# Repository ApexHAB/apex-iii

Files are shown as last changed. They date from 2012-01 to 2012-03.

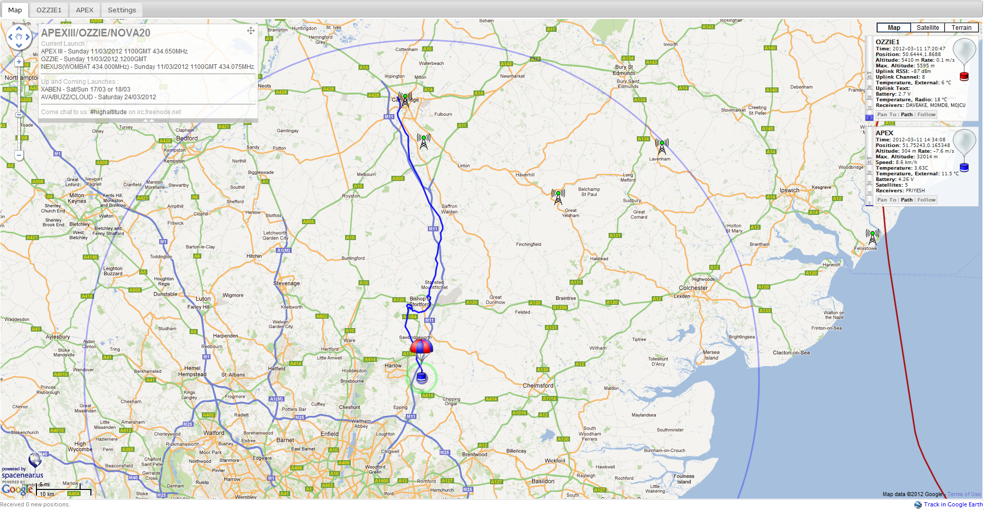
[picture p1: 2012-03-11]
launches/launch-2/track/ApexIIILaunch2-Track (1).png

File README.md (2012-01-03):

# Apex III
## A next generation high altitude balloon project by Sutton Grammar School

## Useful links

* [Homepage](http://www.apexhab.org) - http://www.apexhab.org
* [Apex III Homepage](http://www.apexhab.org/apex-iii/) - http://www.apexhab.org/apex-iii/
* [Contact](mailto:team@apexhab.org) - team@apexhab.org
* [Twitter](http://twitter.com/apexhab) - http://twitter.com/apexhab

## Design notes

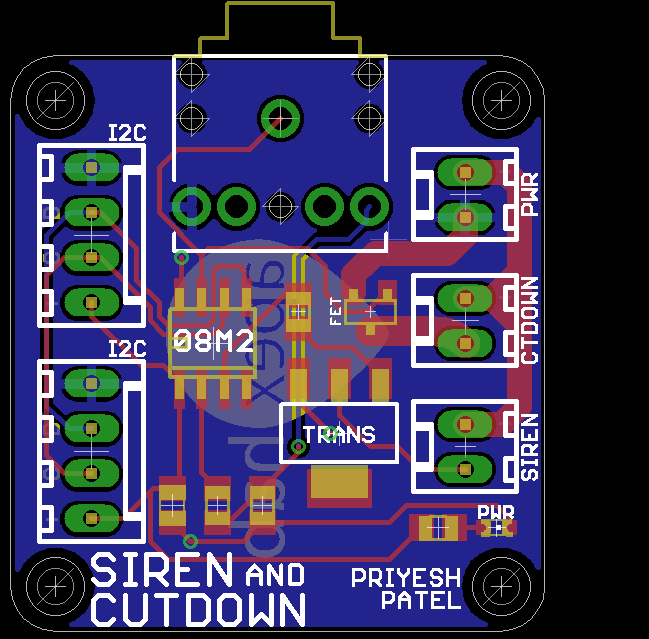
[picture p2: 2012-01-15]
modules/siren_cutdown/pcb/siren-cutdown-brd.png

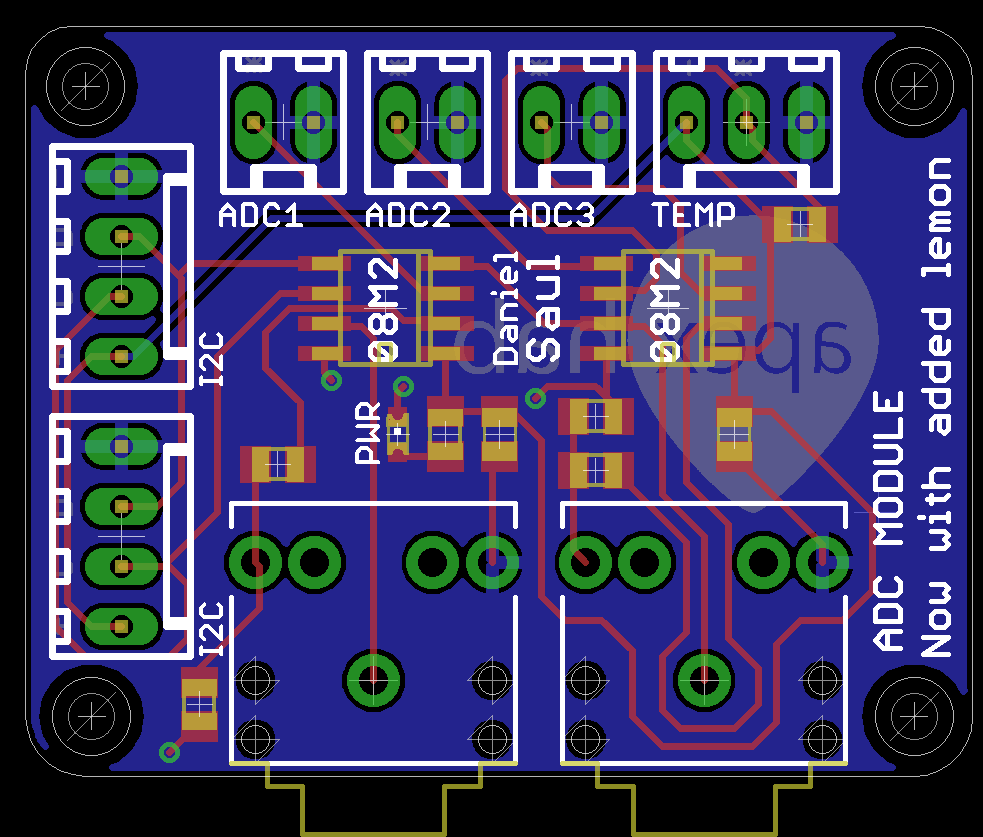
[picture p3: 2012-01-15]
modules/adc_lemon/pcb/adc-lemon-brd.png

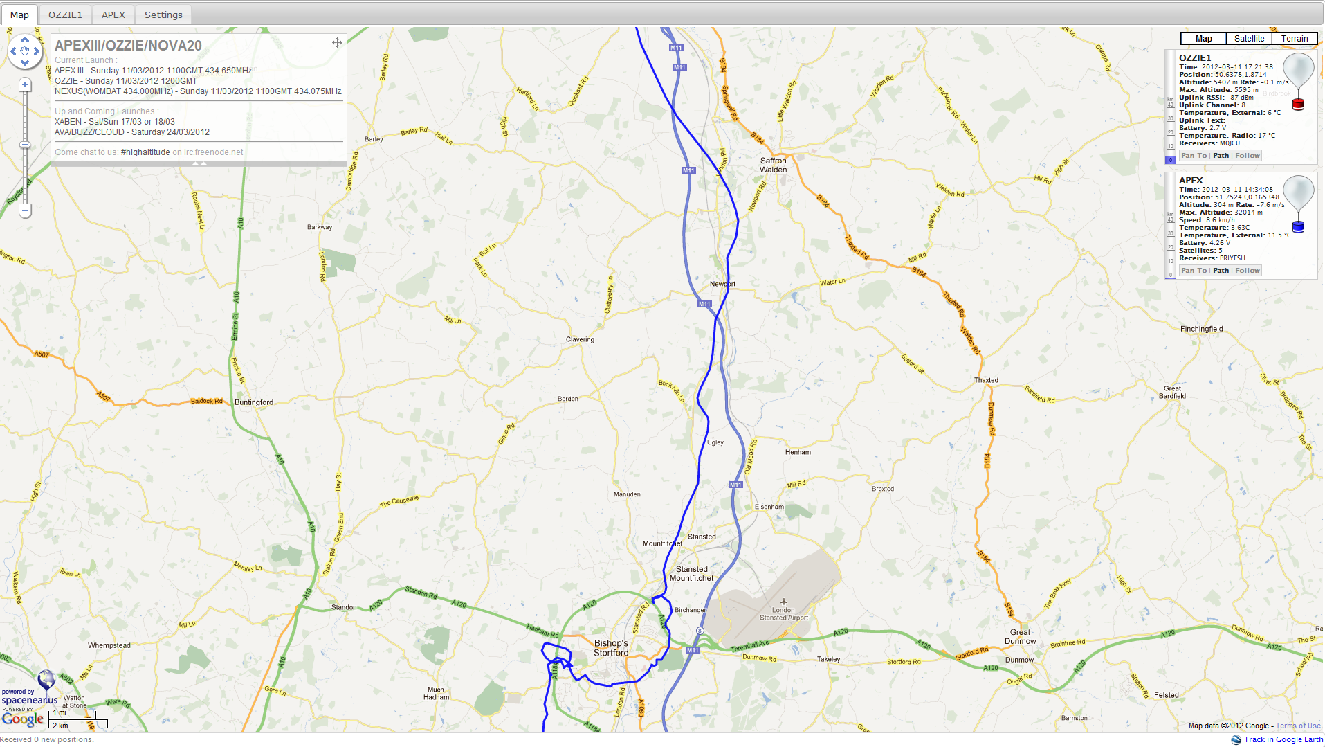
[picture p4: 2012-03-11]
launches/launch-2/track/ApexIIILaunch2-Track (3).png

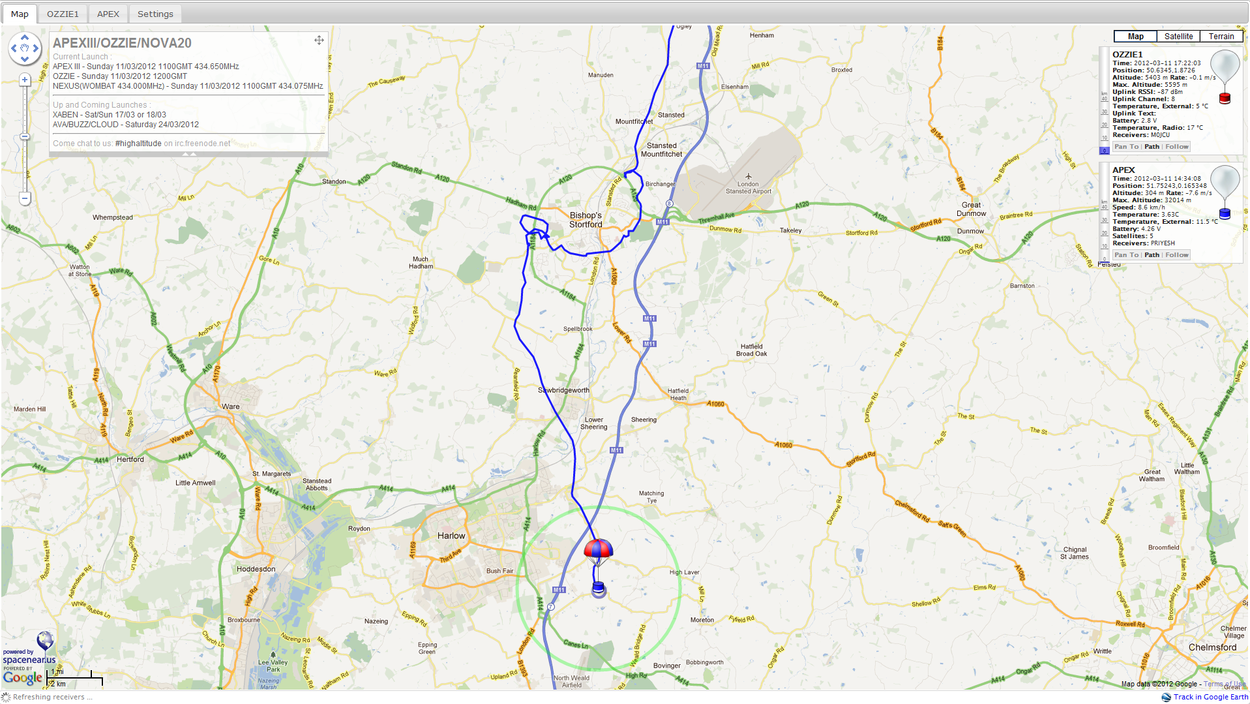
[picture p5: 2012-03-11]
launches/launch-2/track/ApexIIILaunch2-Track (4).png

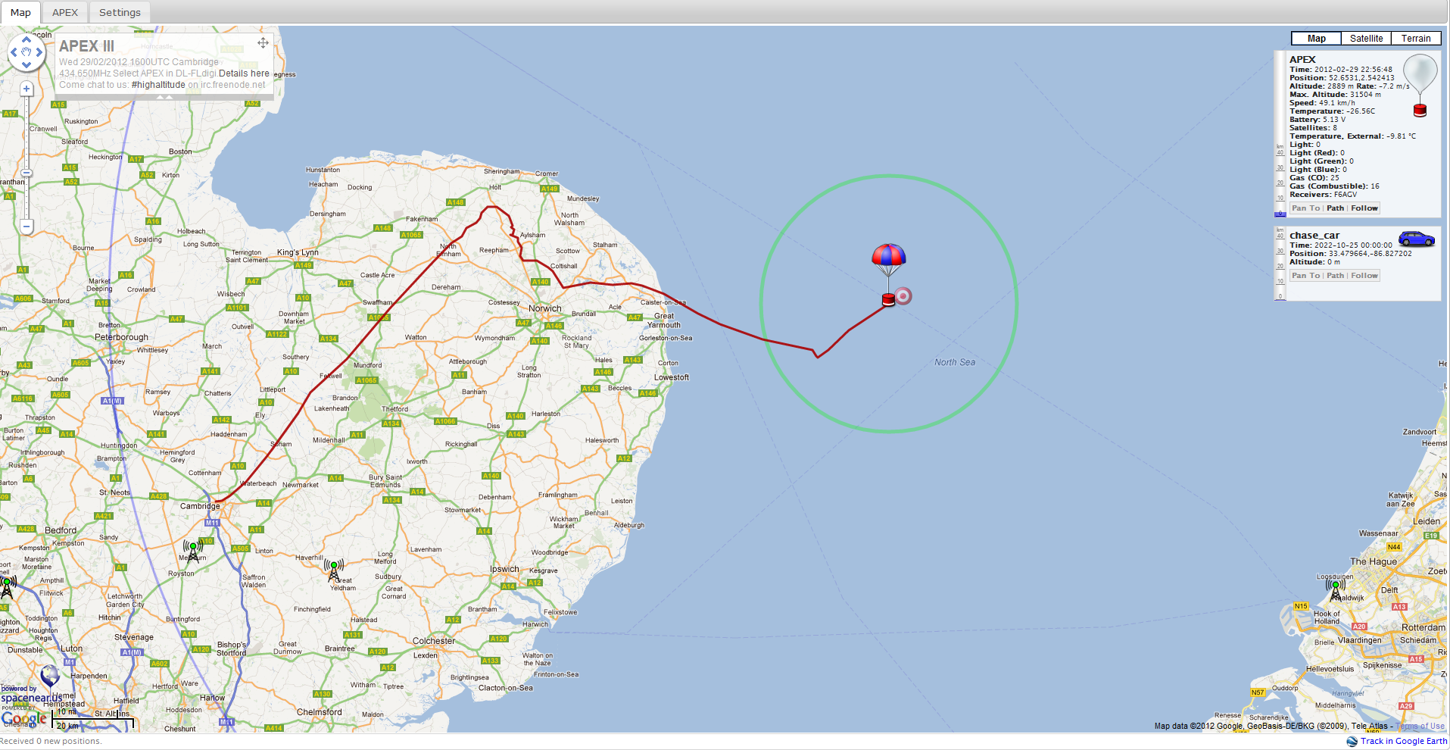
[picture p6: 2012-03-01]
launches/launch-1/track/apex-iii-l1-track-2.png

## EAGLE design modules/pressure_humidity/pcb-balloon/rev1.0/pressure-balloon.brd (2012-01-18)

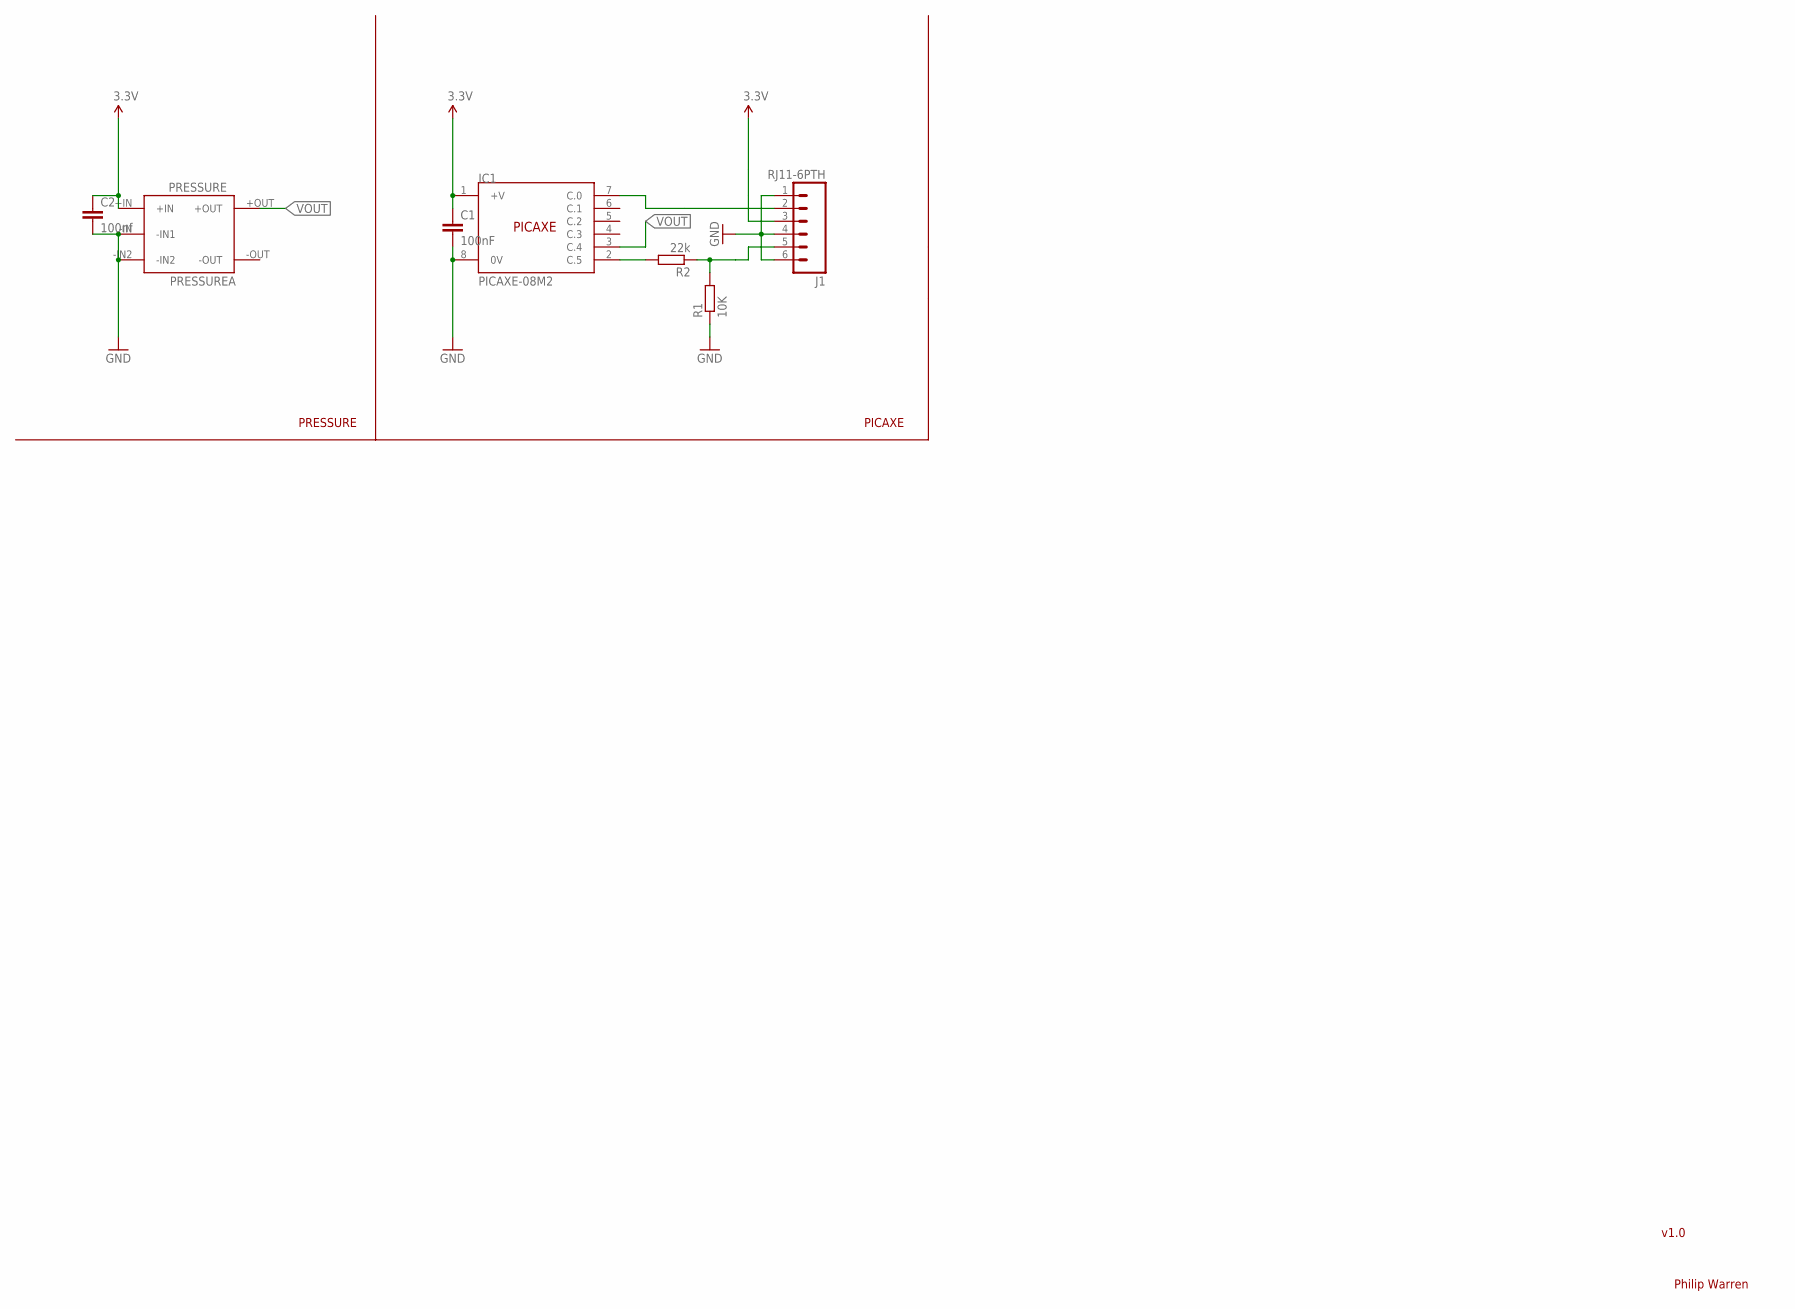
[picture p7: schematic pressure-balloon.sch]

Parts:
C1: 100nF; 0805
C2: 100nf; 0805
IC1: PICAXE-08M2; SOIC8
J1: RJ11-6PTH; RJ11-6
PRESSURE: PRESSUREA; PRESSURE
R1: 10K; R0805
R2: 22k; R0805

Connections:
3.3V: C1.1, C2.1, IC1.1 (+V), J1.3, PRESSURE.+IN
GND: C1.2, C2.2, IC1.8 (0V), J1.1, J1.4, J1.6, PRESSURE.-IN (-IN1), PRESSURE.-IN2, R1.1
unnamed: IC1.7 (C.0), J1.2
unnamed: J1.5, R1.2, R2.1
unnamed: IC1.2 (C.5), R2.2
VOUT: IC1.3 (C.4), PRESSURE.+OUT

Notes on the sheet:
PICAXE
PRESSURE
Philip Warren
v1.0

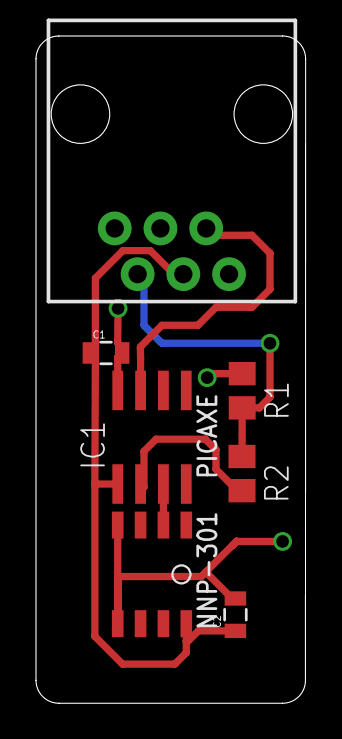
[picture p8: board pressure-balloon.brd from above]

Board: 2 copper layers, 15.0 x 37.1 mm, 7 parts (0 on the bottom side), 6 nets.

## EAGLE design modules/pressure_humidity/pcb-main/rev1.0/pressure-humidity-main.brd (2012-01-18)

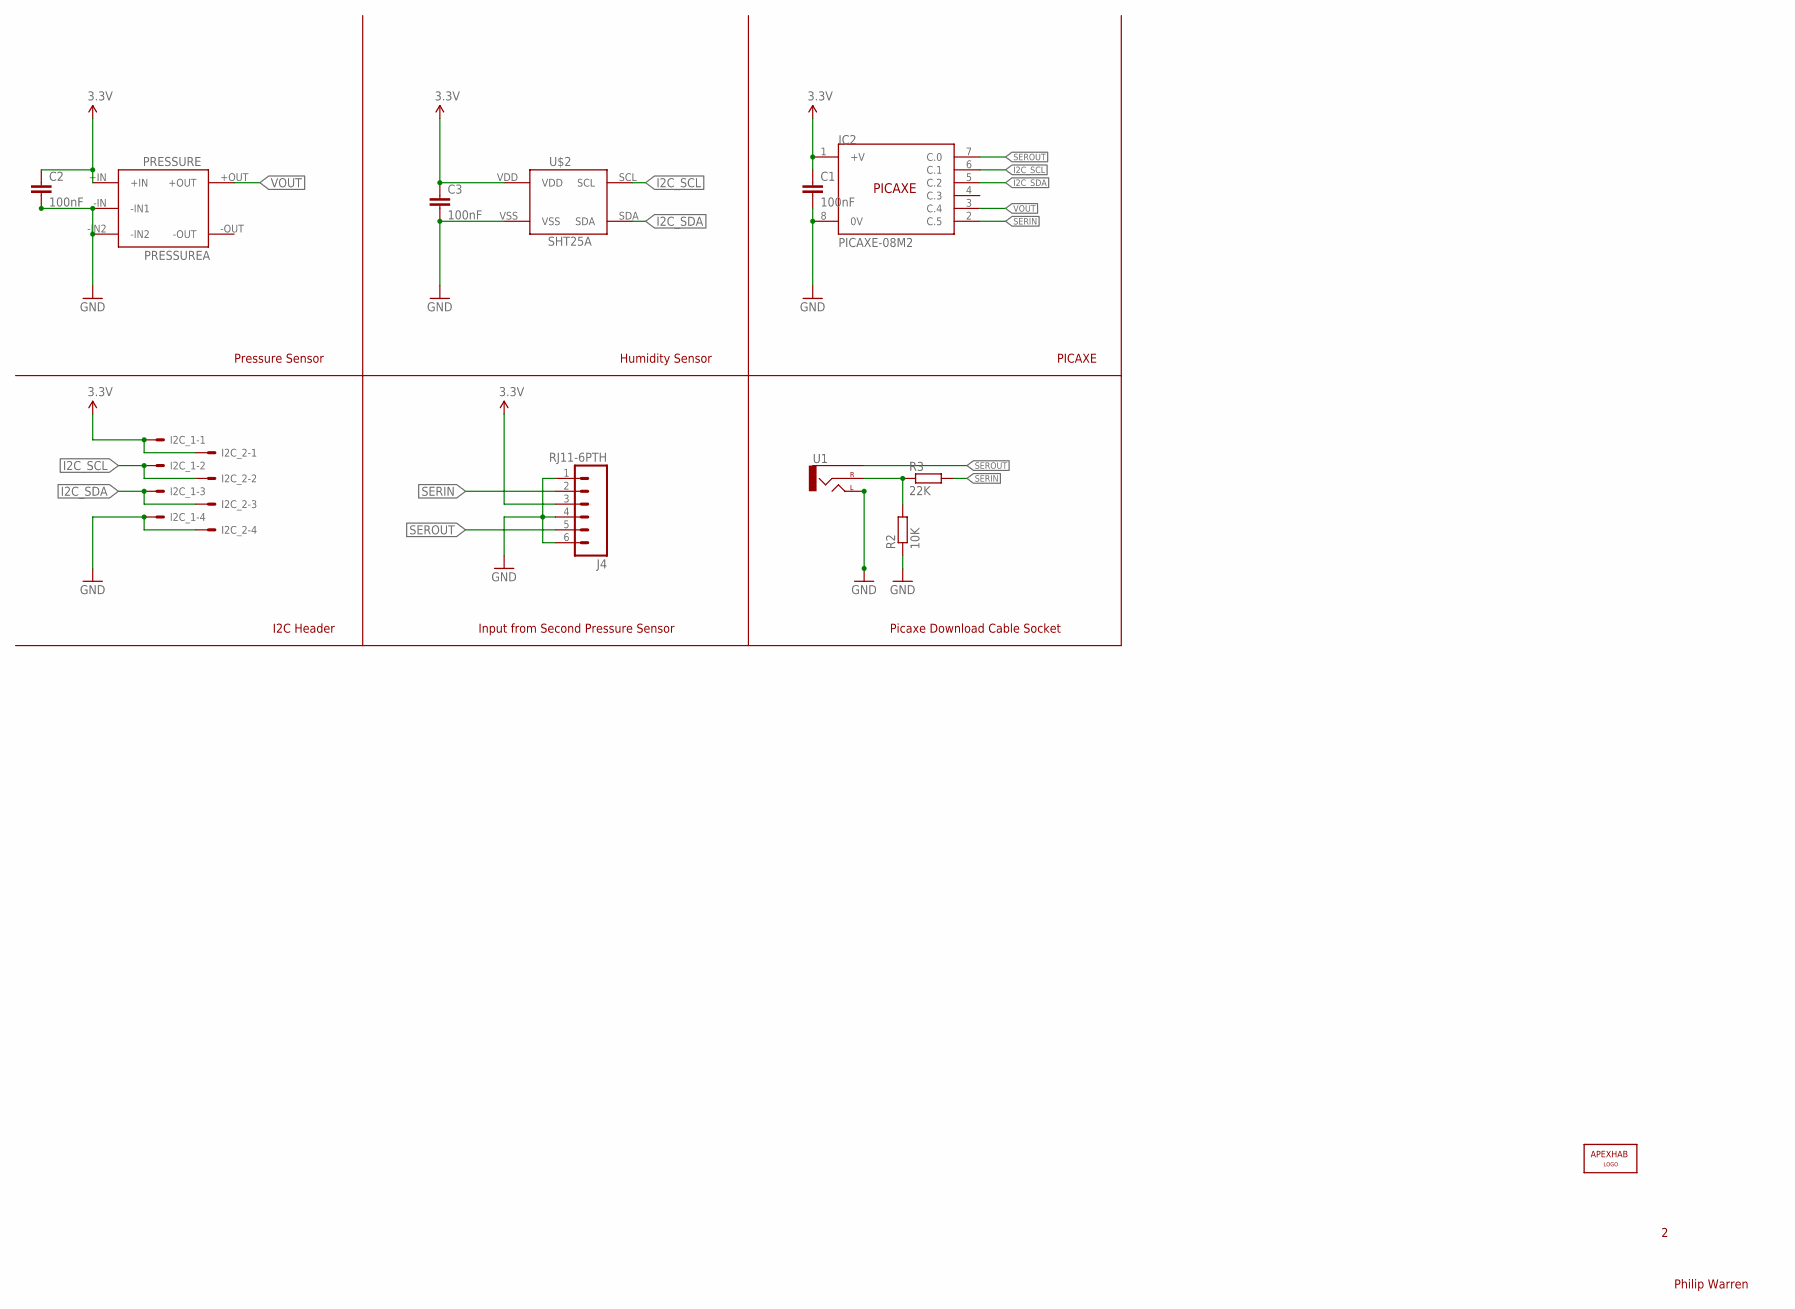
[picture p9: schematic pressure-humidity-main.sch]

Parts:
C1, C2, C3: 100nF; 0805
I2C_1, I2C_2: 22-27-2041-04; 6410-04
IC2: PICAXE-08M2; SOIC8
J4: RJ11-6PTH; RJ11-6
JP1: APEXHAB-LOGO_APEXHAB-SMALL; APEXHAB-LOGO-SMALL
PRESSURE: PRESSUREA; PRESSURE
R2: 10K; R0805
R3: 22K; R0805
U1: AUDIO-JACKPTH; AUDIO-JACK
U$2: SHT25A; SHT25

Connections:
3.3V: C1.1, C2.1, C3.1, I2C_1.1, I2C_2.1, IC2.1 (+V), J4.3, PRESSURE.+IN, U$2.VDD
GND: C1.2, C2.2, C3.2, I2C_1.4, I2C_2.4, IC2.8 (0V), J4.1, J4.4, J4.6, PRESSURE.-IN (-IN1), PRESSURE.-IN2, R2.1, U1.TIP (LEFT), U$2.VSS
I2C_SCL: I2C_1.2, I2C_2.2, IC2.6 (C.1), U$2.SCL
I2C_SDA: I2C_1.3, I2C_2.3, IC2.5 (C.2), U$2.SDA
unnamed: R2.2, R3.1, U1.RING (RIGHT)
SERIN: IC2.2 (C.5), J4.2, R3.2
SEROUT: IC2.7 (C.0), J4.5, U1.SLEEVE
VOUT: IC2.3 (C.4), PRESSURE.+OUT

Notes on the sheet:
Pressure Sensor
Humidity Sensor
PICAXE
Picaxe Download Cable Socket
Input from Second Pressure Sensor
I2C Header
Philip Warren

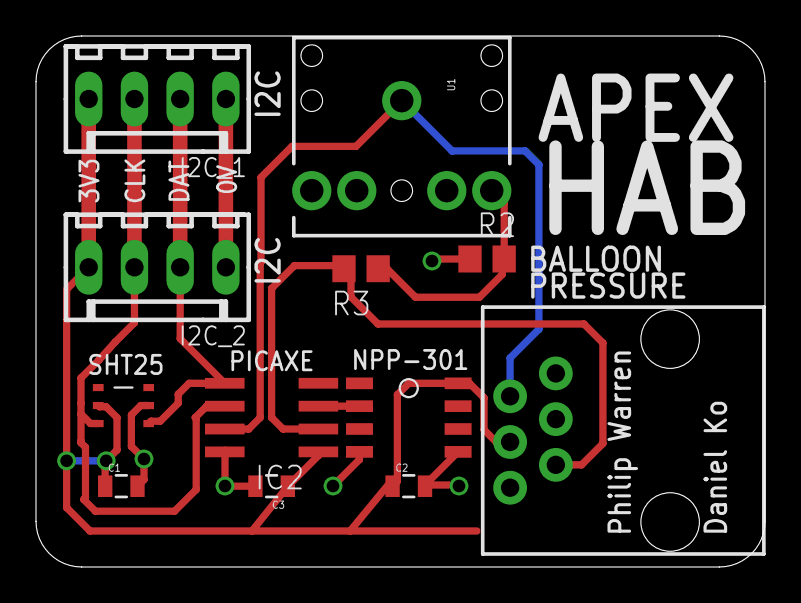
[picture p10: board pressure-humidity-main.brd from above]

Board: 2 copper layers, 40.5 x 29.5 mm, 13 parts (1 on the bottom side), 8 nets.

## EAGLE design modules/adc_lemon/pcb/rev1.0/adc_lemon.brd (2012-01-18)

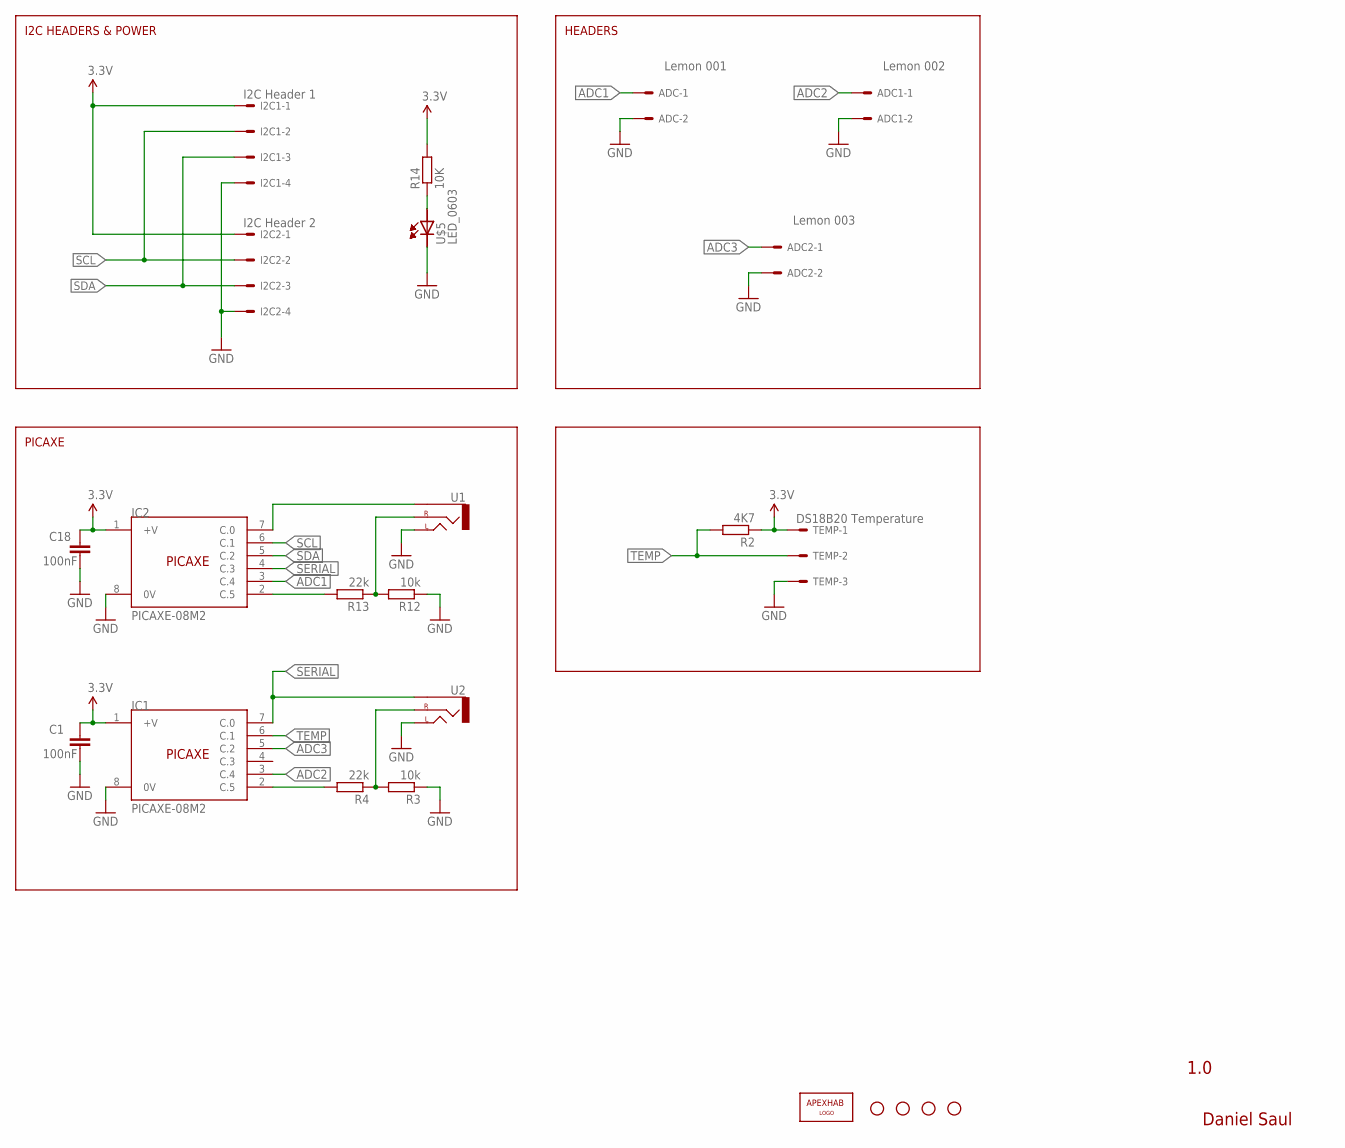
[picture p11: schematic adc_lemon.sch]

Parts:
ADC: Lemon 001; 6410-02
ADC1: Lemon 002; 6410-02
ADC2: Lemon 003; 6410-02
C1, C18: 100nF; C0805
I2C1: I2C Header 1; 6410-04
I2C2: I2C Header 2; 6410-04
IC1, IC2: PICAXE-08M2; SOIC8
JP1: APEXHAB-LOGO_APEXHAB-SMALL; APEXHAB-LOGO-SMALL
JP2, JP3, JP4, JP5: STAND-OFF
R2: 4K7; R0805
R3, R12: 10k; R0805
R4, R13: 22k; R0805
R14: 10K; R0805
TEMP: DS18B20 Temperature; 6410-03
U1, U2: AUDIO-JACKPTH; AUDIO-JACK
U$5: LED_0603; CHIPLED_0603

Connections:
3.3V: C1.1, C18.1, I2C1.1, I2C2.1, IC1.1 (+V), IC2.1 (+V), R2.1, R14.2, TEMP.1
ADC1: ADC.1, IC2.3 (C.4)
ADC2: ADC1.1, IC1.3 (C.4)
ADC3: ADC2.1, IC1.5 (C.2)
GND: ADC.2, ADC1.2, ADC2.2, C1.2, C18.2, I2C1.4, I2C2.4, IC1.8 (0V), IC2.8 (0V), R3.1, R12.1, TEMP.3, U1.TIP (LEFT), U2.TIP (LEFT), U$5.C
unnamed: IC1.2 (C.5), R4.2
unnamed: R3.2, R4.1, U2.RING (RIGHT)
unnamed: IC2.2 (C.5), R13.2
unnamed: IC2.7 (C.0), U1.SLEEVE
unnamed: R12.2, R13.1, U1.RING (RIGHT)
unnamed: R14.1, U$5.A
SCL: I2C1.2, I2C2.2, IC2.6 (C.1)
SDA: I2C1.3, I2C2.3, IC2.5 (C.2)
SERIAL: IC1.7 (C.0), IC2.4 (C.3), U2.SLEEVE
TEMP: IC1.6 (C.1), R2.2, TEMP.2

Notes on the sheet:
1.0
Daniel Saul
I2C HEADERS & POWER
HEADERS
PICAXE

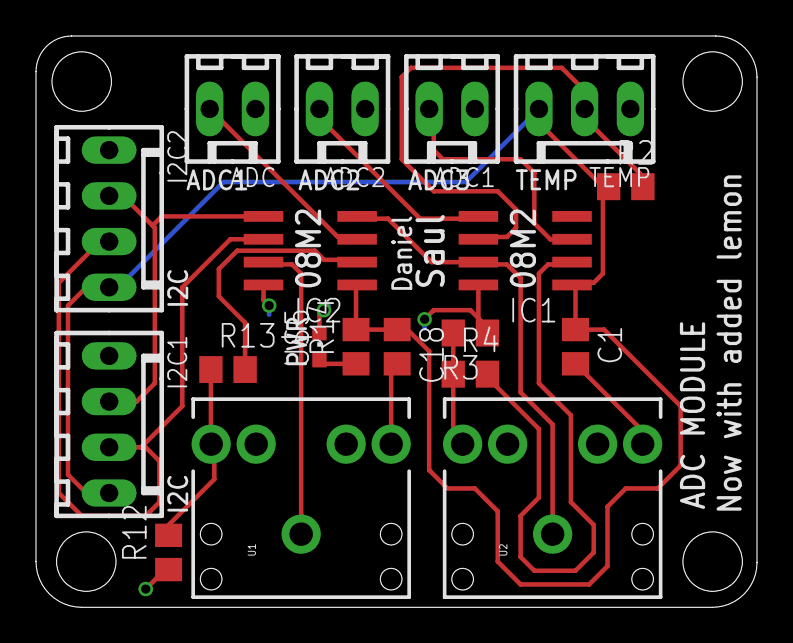
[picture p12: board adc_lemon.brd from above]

Board: 2 copper layers, 40.1 x 31.7 mm, 24 parts (1 on the bottom side), 15 nets.

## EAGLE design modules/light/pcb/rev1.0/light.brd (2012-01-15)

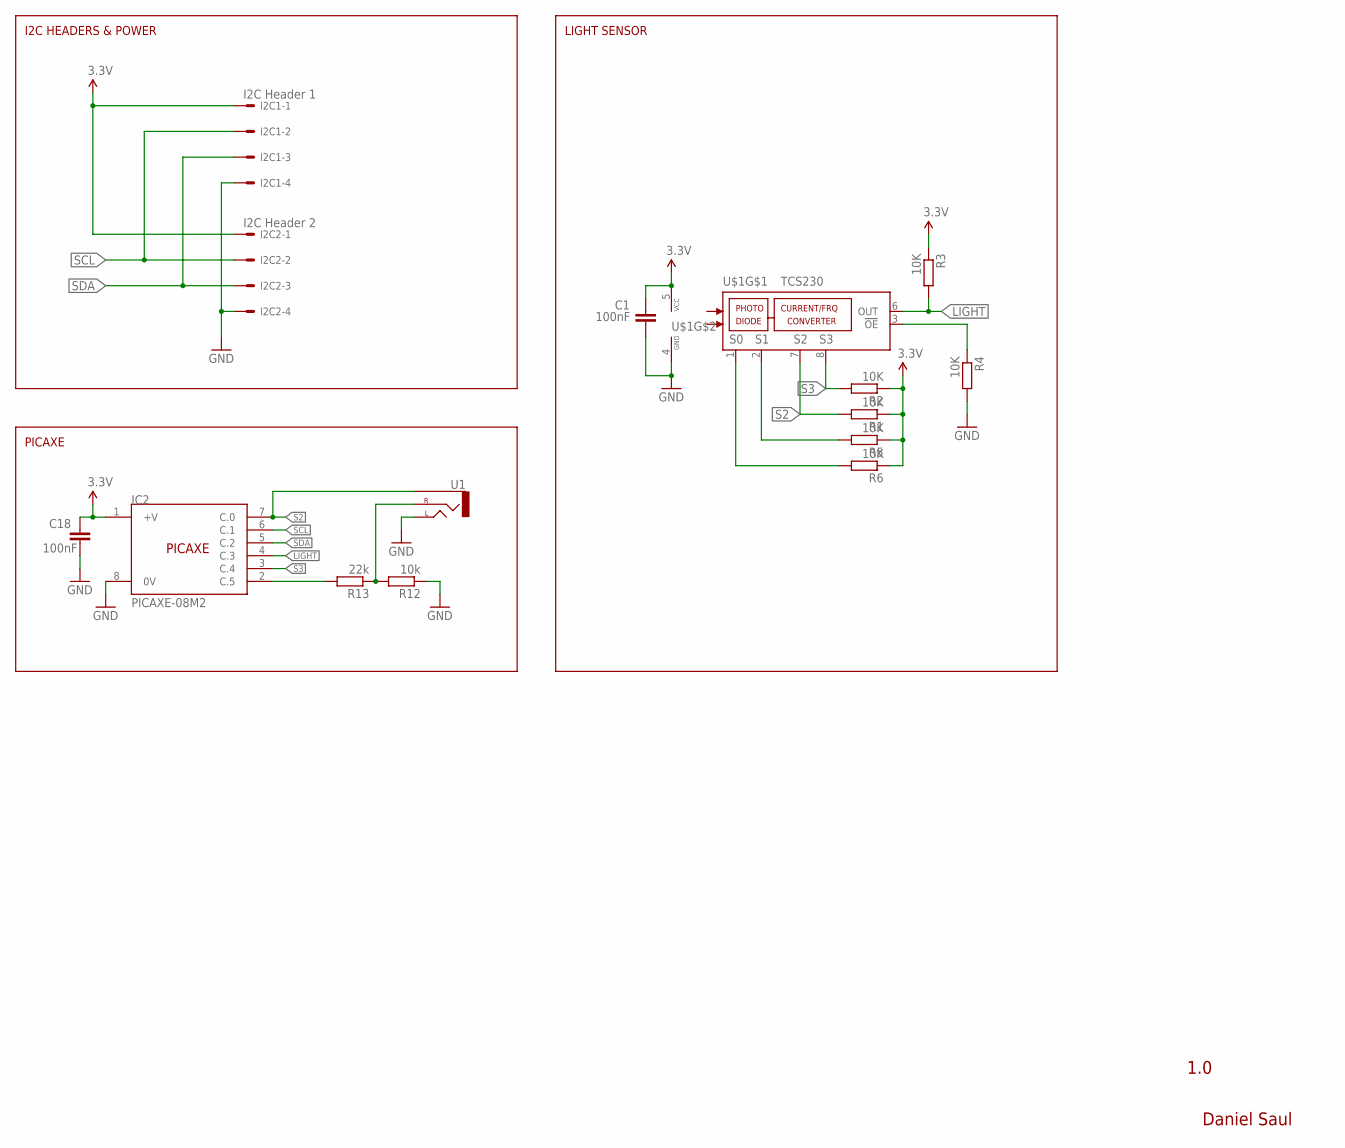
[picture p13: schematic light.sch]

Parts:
C1, C18: 100nF; C0805
I2C1: I2C Header 1; 6410-04
I2C2: I2C Header 2; 6410-04
IC2: PICAXE-08M2; SOIC8
R1, R2, R3, R4, R5, R6: 10K; R0805
R12: 10k; R0805
R13: 22k; R0805
U1: AUDIO-JACKPTH; AUDIO-JACK
U$1: TCS230; SOIC8

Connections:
3.3V: C1.1, C18.1, I2C1.1, I2C2.1, IC2.1 (+V), R1.1, R2.1, R3.1, R5.1, R6.1, U$1.5 (VCC)
GND: C1.2, C18.2, I2C1.4, I2C2.4, IC2.8 (0V), R4.2, R12.1, U1.TIP (LEFT), U$1.4 (GND)
LIGHT: IC2.4 (C.3), R3.2, U$1.6 (OUT)
unnamed: R5.2, U$1.2 (S1)
unnamed: R4.1, U$1.3 (!OE)
unnamed: R6.2, U$1.1 (S0)
unnamed: IC2.2 (C.5), R13.2
unnamed: R12.2, R13.1, U1.RING (RIGHT)
S2: IC2.7 (C.0), R1.2, U1.SLEEVE, U$1.7 (S2)
S3: IC2.3 (C.4), R2.2, U$1.8 (S3)
SCL: I2C1.2, I2C2.2, IC2.6 (C.1)
SDA: I2C1.3, I2C2.3, IC2.5 (C.2)

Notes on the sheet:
1.0
Daniel Saul
I2C HEADERS & POWER
PICAXE
LIGHT SENSOR

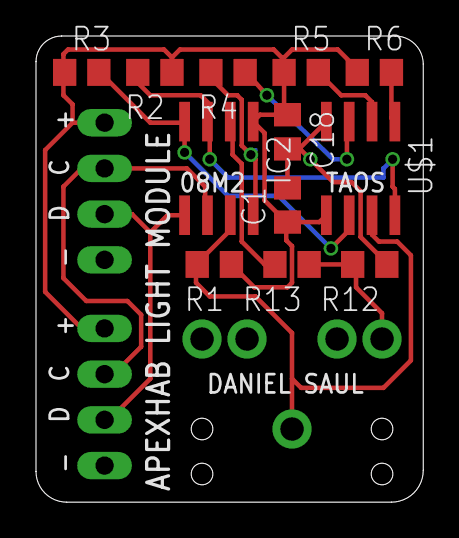
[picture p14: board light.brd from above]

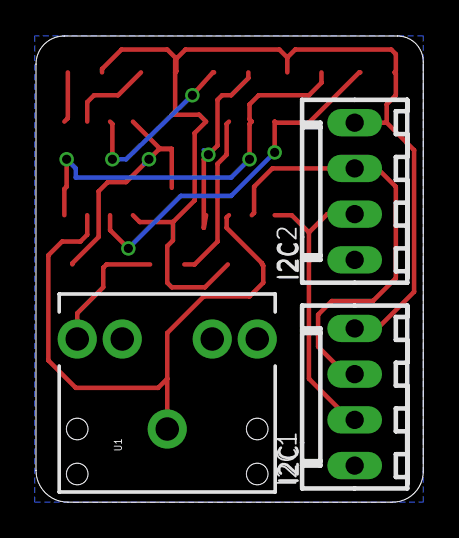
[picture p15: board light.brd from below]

Board: 2 copper layers, 21.5 x 25.9 mm, 15 parts (3 on the bottom side), 12 nets.

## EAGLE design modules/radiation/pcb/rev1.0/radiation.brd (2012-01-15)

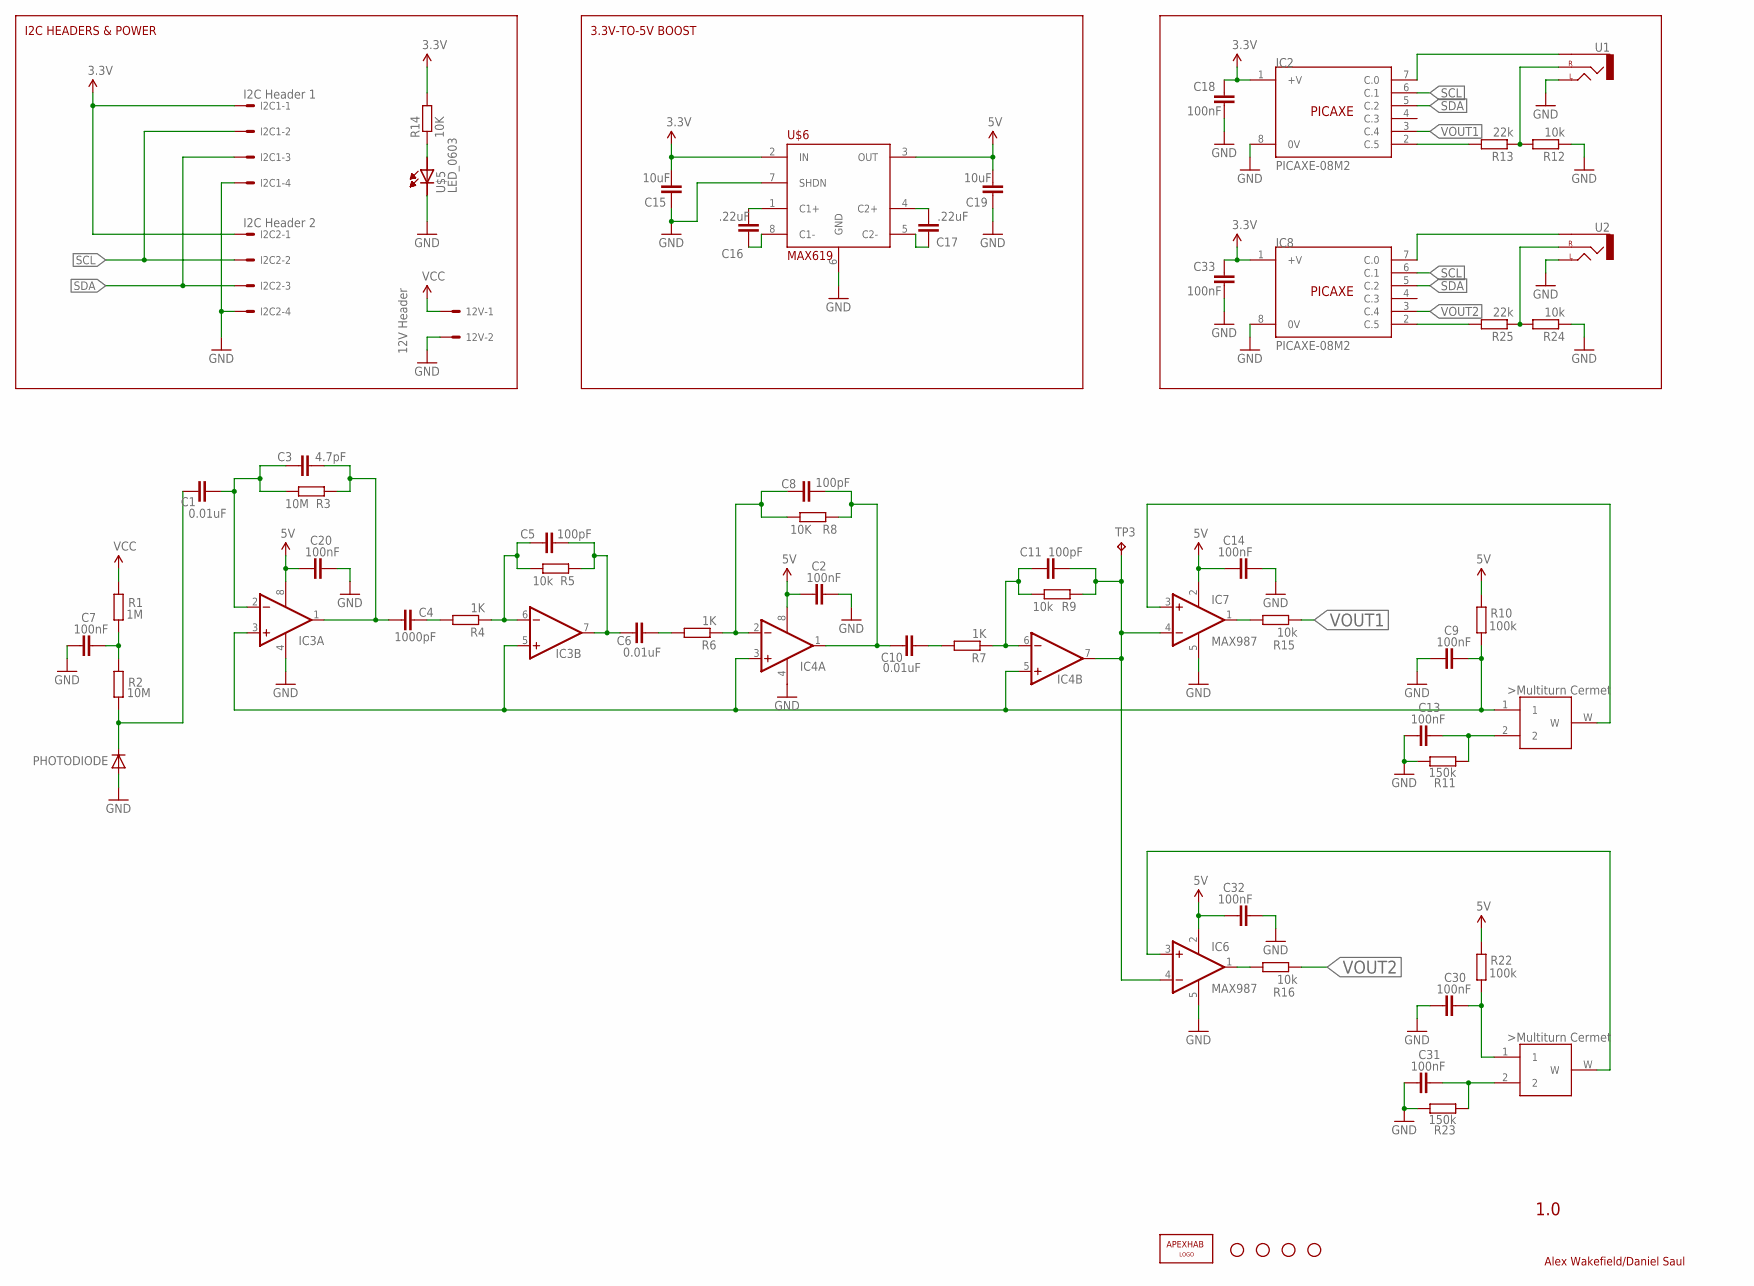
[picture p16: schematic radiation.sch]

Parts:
12V: 12V Header; 6410-02
C1, C6, C10: 0.01uF; C0805
C2, C7, C9, C13, C14, C18, C20, C30, C31, C32, C33: 100nF; C0805
C3: 4.7pF; C0805
C4: 1000pF; C0805
C5, C8, C11: 100pF; C0805
C15, C19: 10uF; C0805
C16, C17: .22uF; C0805
I2C1: I2C Header 1; 6410-04
I2C2: I2C Header 2; 6410-04
IC2, IC8: PICAXE-08M2; SOIC8
IC3: max4477; SO08
IC4: <AX4477; SO08
IC6, IC7: MAX987; SOT23-5
JP1: APEXHAB-LOGO_APEX; APEX-LOGO
JP2, JP3, JP4, JP5: STAND-OFF
PHOTODIODE: DIODE-D-2.5; D-2.5
R1: 1M; R0805
R2, R3: 10M; R0805
R4, R6, R7: 1K; R0805
R5, R9, R12, R15, R16, R24: 10k; R0805
R8, R14: 10K; R0805
R10, R22: 100k; R0805
R11, R23: 150k; R0805
R13, R25: 22k; R0805
TP3: TPTP10SQ; TP10SQ
U1, U2: AUDIO-JACKPTH; AUDIO-JACK
U$3, U$4: YL_SMT_11-TURN_CERMET_TRIMMER,_10K_0.25W
U$5: LED_0603; CHIPLED_0603
U$6: MAX619; SO8

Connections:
3.3V: C15.2, C18.1, C33.1, I2C1.1, I2C2.1, IC2.1 (+V), IC8.1 (+V), R14.2, U$6.2 (IN)
5V: C2.1, C14.1, C19.2, C20.1, C32.1, IC3.8 (V+), IC4.8 (V+), IC6.2 (V+), IC7.2 (V+), R10.1, R22.1, U$6.3 (OUT)
GND: 12V.2, C2.2, C7.1, C9.1, C13.1, C14.2, C15.1, C18.2, C19.1, C20.2, C30.1, C31.1, C32.2, C33.2, I2C1.4, I2C2.4, IC2.8 (0V), IC3.4 (V-), IC4.4 (V-), IC6.5 (V-), IC7.5 (V-), IC8.8 (0V), PHOTODIODE.A, R11.2, R12.1, R23.2, R24.1, U1.TIP (LEFT), U2.TIP (LEFT), U$5.C, U$6.6 (GND), U$6.7 (SHDN)
unnamed: C7.2, R1.1, R2.2
unnamed: C1.1, PHOTODIODE.C, R2.1
unnamed: C1.2, C3.1, IC3.2 (-IN), R3.2
unnamed: C4.2, R4.2
unnamed: C3.2, C4.1, IC3.1 (OUT), R3.1
unnamed: C5.1, IC3.6 (-IN), R4.1, R5.2
unnamed: C6.2, R6.2
unnamed: C5.2, C6.1, IC3.7 (OUT), R5.1
unnamed: C8.1, IC4.2 (-IN), R6.1, R8.2
unnamed: C13.2, R11.1, U$4.2
unnamed: C10.2, R7.2
unnamed: C11.1, IC4.6 (-IN), R7.1, R9.2
unnamed: IC8.7 (C.0), U2.SLEEVE
unnamed: IC7.3 (+IN), U$4.W
unnamed: C30.2, R22.2, U$3.1
unnamed: IC7.1 (OUT), R15.2
unnamed: IC2.2 (C.5), R13.2
unnamed: IC2.7 (C.0), U1.SLEEVE
unnamed: IC8.2 (C.5), R25.2
unnamed: R12.2, R13.1, U1.RING (RIGHT)
unnamed: R14.1, U$5.A
unnamed: C16.2, U$6.1 (C1+)
unnamed: C16.1, U$6.8 (C1-)
unnamed: C17.2, U$6.4 (C2+)
unnamed: C17.1, U$6.5 (C2-)
unnamed: C11.2, IC4.7 (OUT), IC6.4 (-IN), IC7.4 (-IN), R9.1, TP3.TP
unnamed: IC6.1 (OUT), R16.2
unnamed: C8.2, C10.1, IC4.1 (OUT), R8.1
unnamed: C9.2, IC3.3 (+IN), IC3.5 (+IN), IC4.3 (+IN), IC4.5 (+IN), R10.2, U$4.1
unnamed: C31.2, R23.1, U$3.2
unnamed: IC6.3 (+IN), U$3.W
unnamed: R24.2, R25.1, U2.RING (RIGHT)
SCL: I2C1.2, I2C2.2, IC2.6 (C.1), IC8.6 (C.1)
SDA: I2C1.3, I2C2.3, IC2.5 (C.2), IC8.5 (C.2)
VCC: 12V.1, R1.2
VOUT1: IC2.3 (C.4), R15.1
VOUT2: IC8.3 (C.4), R16.1

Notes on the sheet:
1.0
Alex Wakefield/Daniel Saul
I2C HEADERS & POWER
3.3V-TO-5V BOOST

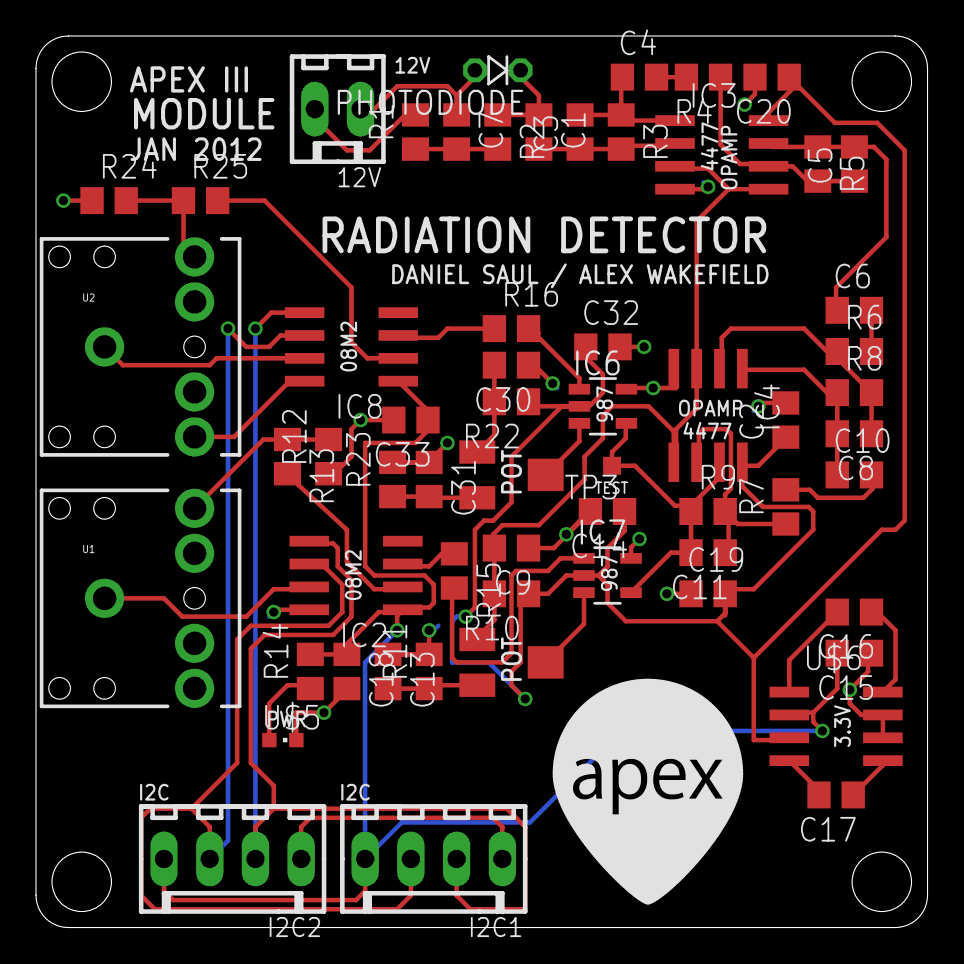
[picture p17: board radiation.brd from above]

Board: 2 copper layers, 49.5 x 49.5 mm, 65 parts (0 on the bottom side), 40 nets.

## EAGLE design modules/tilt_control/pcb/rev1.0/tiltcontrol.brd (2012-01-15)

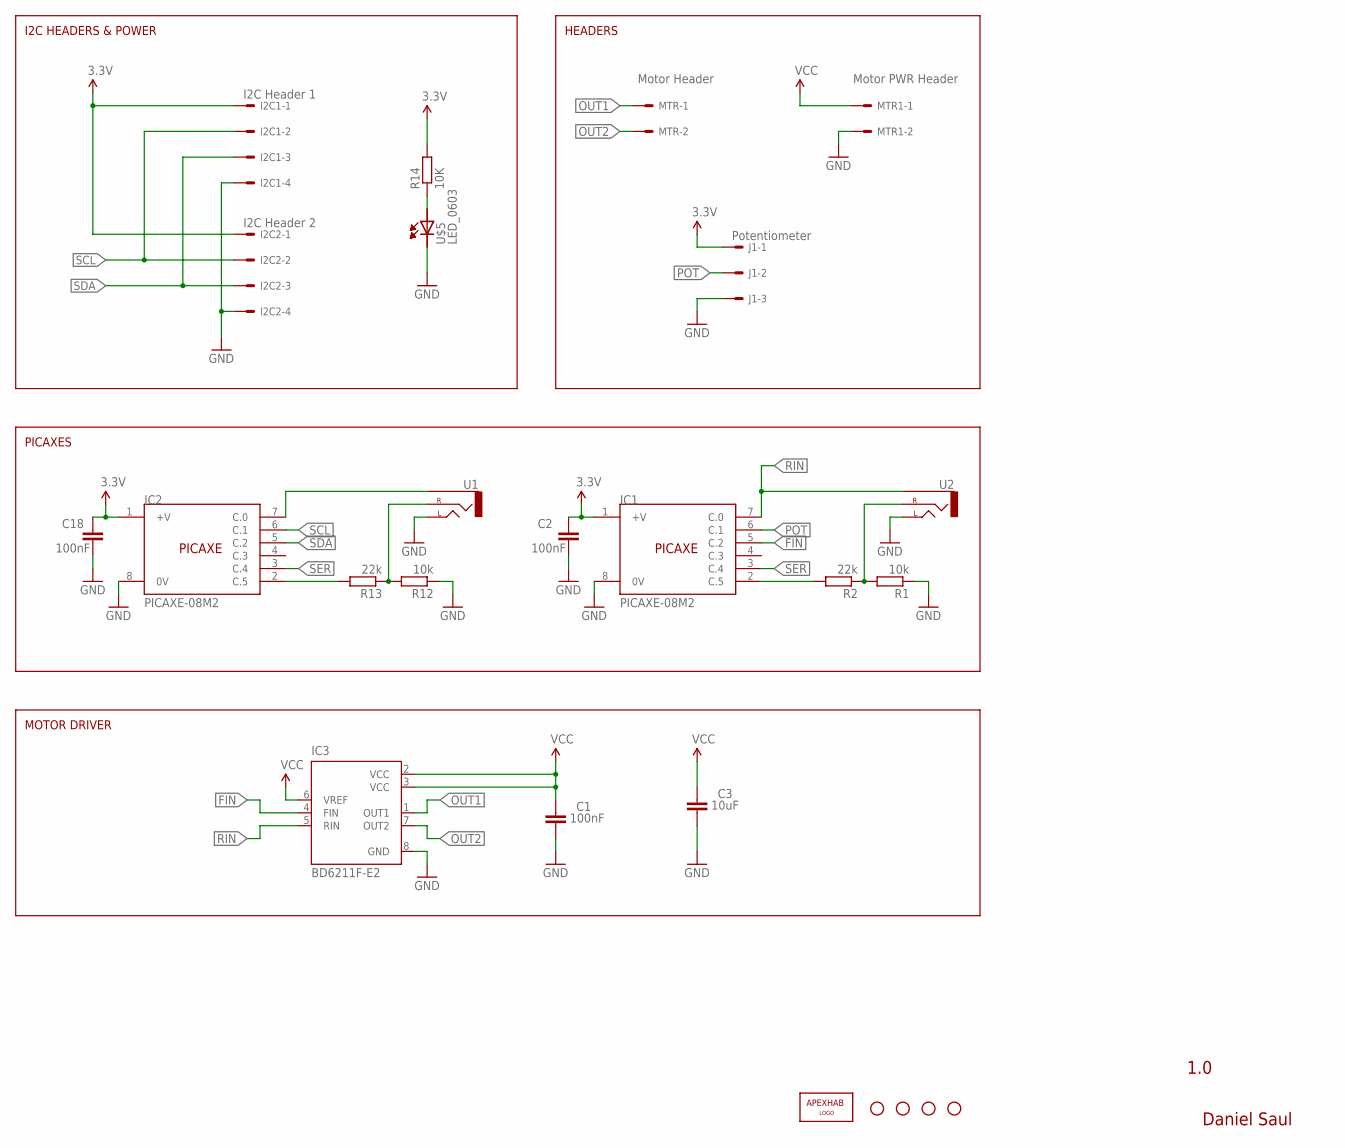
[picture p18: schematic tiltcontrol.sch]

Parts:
C1, C2, C18: 100nF; C0805
C3: 10uF; C0805
I2C1: I2C Header 1; 6410-04
I2C2: I2C Header 2; 6410-04
IC1, IC2: PICAXE-08M2; SOIC8
IC3: BD6211F-E2; SOP8
J1: Potentiometer; 6410-03
JP1: APEXHAB-LOGO_APEXHAB-SMALL; APEXHAB-LOGO-SMALL
JP2, JP3, JP4, JP5: STAND-OFF
MTR: Motor Header; 6410-02
MTR1: Motor PWR Header; 6410-02
R1, R12: 10k; R0805
R2, R13: 22k; R0805
R14: 10K; R0805
U1, U2: AUDIO-JACKPTH; AUDIO-JACK
U$5: LED_0603; CHIPLED_0603

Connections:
3.3V: C2.1, C18.1, I2C1.1, I2C2.1, IC1.1 (+V), IC2.1 (+V), J1.1, R14.2
FIN: IC1.5 (C.2), IC3.4 (FIN)
GND: C1.2, C2.2, C3.2, C18.2, I2C1.4, I2C2.4, IC1.8 (0V), IC2.8 (0V), IC3.8 (GND), J1.3, MTR1.2, R1.1, R12.1, U1.TIP (LEFT), U2.TIP (LEFT), U$5.C
unnamed: IC1.2 (C.5), R2.2
unnamed: R1.2, R2.1, U2.RING (RIGHT)
unnamed: IC2.2 (C.5), R13.2
unnamed: IC2.7 (C.0), U1.SLEEVE
unnamed: R12.2, R13.1, U1.RING (RIGHT)
unnamed: R14.1, U$5.A
OUT1: IC3.1 (OUT1), MTR.1
OUT2: IC3.7 (OUT2), MTR.2
POT: IC1.6 (C.1), J1.2
RIN: IC1.7 (C.0), IC3.5 (RIN), U2.SLEEVE
SCL: I2C1.2, I2C2.2, IC2.6 (C.1)
SDA: I2C1.3, I2C2.3, IC2.5 (C.2)
SER: IC1.3 (C.4), IC2.3 (C.4)
VCC: C1.1, C3.1, IC3.2 (VCC), IC3.3 (VCC), IC3.6 (VREF), MTR1.1

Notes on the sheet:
1.0
Daniel Saul
I2C HEADERS & POWER
HEADERS
PICAXES
MOTOR DRIVER


Board: 2 copper layers, 50.0 x 36.5 mm, 25 parts (0 on the bottom side), 17 nets.

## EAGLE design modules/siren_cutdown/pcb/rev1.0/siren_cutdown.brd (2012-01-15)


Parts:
C18: 100nF; C0805
CUTDOWN: Cutdown; 6410-02
I2C1: I2C Header 1; 6410-04
I2C2: I2C Header 2; 6410-04
IC2: PICAXE-08M2; SOIC8
JP1: APEXHAB-LOGO_APEXHAB-SMALL; APEXHAB-LOGO-SMALL
JP2, JP3, JP4, JP5: STAND-OFF
MOSFET: TRANSISTOR_NPNSOT23; SOT23
PWR: Siren-Power; 6410-02
PWR_LED: LED_0603; CHIPLED_0603
PWR_RES: 1K5; R0805
Q1: TRANSISTOR_NPN"; SOT223
R1: 1K; R0805
R12: 10k; R0805
R13: 22k; R0805
SIREN: Siren; 6410-02
U1: AUDIO-JACKPTH; AUDIO-JACK

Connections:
3.3V: C18.1, I2C1.1, I2C2.1, IC2.1 (+V), PWR_RES.2
CUTDOWN: IC2.7 (C.0), MOSFET.1 (B), U1.SLEEVE
GND: C18.2, I2C1.4, I2C2.4, IC2.8 (0V), MOSFET.2 (E), PWR.2, PWR_LED.C, Q1.3 (E), R12.1, U1.TIP (LEFT)
unnamed: Q1.1 (B), R1.1
unnamed: Q1.2 (C), SIREN.2
unnamed: CUTDOWN.2, MOSFET.3 (C)
unnamed: IC2.2 (C.5), R13.2
unnamed: R12.2, R13.1, U1.RING (RIGHT)
unnamed: PWR_LED.A, PWR_RES.1
SCL: I2C1.2, I2C2.2, IC2.6 (C.1)
SDA: I2C1.3, I2C2.3, IC2.5 (C.2)
SIREN: IC2.3 (C.4), R1.2
VCC: CUTDOWN.1, PWR.1, SIREN.1

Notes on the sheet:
Priyesh Patel
v1.0
I2C HEADERS & POWER LED
PICAXE
SIREN
POWER
CUTDOWN


Board: 2 copper layers, 30.1 x 32.5 mm, 20 parts (1 on the bottom side), 13 nets.

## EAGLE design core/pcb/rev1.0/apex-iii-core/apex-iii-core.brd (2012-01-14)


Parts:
1WIRE: 4K7; R0805
ANLG_HDR1: ANLG_HDR1; 6410-04
ANLG_HDR2: ANLG_HDR2; 6410-04
ARDUINO-ATMEGA328: ATMEGA328; TQFP32-08
BATT: 33K; R0805
BATT2: 22K; R0805
BATT3: 100nF; 0805
C1: 10uF; 0805
C2: 1uF; 0805
C3: 0.01uF; 0805
C4, C5: 18pF; 0805
C6, C7, C8, C10: 100nF; 0805
CS_PULL_UP: 4K7; R0805
DGTL_HDR: DGTL_HDR; 6410-03
EXT_TX: EXT_TX; 6410-03
FTDI: FTDI_BASICPTH; FTDI_BASIC
GPS: LASSEN_IQ_GPSLASSEN; LASSEN_IQ_GPS
GPS_DCPLG: 100nF; 0805
GPS_RES1, GPS_RES2: 100K; R0805
GPS_RES3: 1K; R0805
I2C-1: I2C_1; 6410-04
I2C-2: I2C_2; 6410-04
I2C_RES1, I2C_RES2: 4K7; R0805
ICSP: AVR-ISP-6
INTERNAL_TEMP: DS18B20Z; SO08
JP1, JP2, JP3, JP4: STAND-OFF
JP5: APEXHAB-LOGO_APEXHAB-SMALL; APEXHAB-LOGO-SMALL
JP6: APEXHAB-LOGO_APEXHAB; APEXHAB-LOGO
LED_PWR: GREEN; CHIPLED_0603
MICRO-SD: USD-SOCKET; MICRO-SD-PUSH-PULL
MISO_RES: 1K; R0805
NTR2: NTR2
NTR2_DCPLG1: 100nF; 0805
NTR2_DCPLG2: 47uF; 0805
NTR2_RES1, NTR2_RES3: 22K; R0805
NTR2_RES2: 6K8; R0805
NTR2_RES4: 10K; R0805
OPAMP: MAX4477; SO08
OSC: 16MHz; CRYSTAL-SMD-5X3
P: DC-IN; 6410-02
R1, R2: 100K; RTRIM3214W
RESET: SW-MOMENTARY-SMD; TACTILE-SWITCH-1101NE
RES_PWR: 1K5; R0805
SD_DCPLG: 100nF; 0805
SMA_CONN: SMA-142-0701-801/806; J502-ND-142-0701-801/806
STATUS_LED: GREEN; CHIPLED_0603
STATUS_RES: 1K5; R0805
TEMPADD: ADDITIONAL_TEMP; 6410-03
TEMPEXT: EXTERNAL_TEMP; 6410-03
TEMP_DCPLG: 100nF; 0805
UP_CAP1, UP_CAP3, UP_CAP4: 47nF; 0805
UP_RES1: 10K; R0805
UP_RES2: 1K; R0805
UP_RES4: 1K5; R0805
VREG: LT1763CS8-3.3; SOIC8

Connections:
ANLG2: ANLG_HDR2.3, ARDUINO-ATMEGA328.25 (ANALOG_2)
ANLG3: ANLG_HDR2.4, ARDUINO-ATMEGA328.26 (ANALOG_3)
ANLG6: ANLG_HDR1.3, ARDUINO-ATMEGA328.19 (ANALOG_6)
ANLG7: ANLG_HDR1.4, ARDUINO-ATMEGA328.22 (ANALOG_7)
AVR_RESET: ARDUINO-ATMEGA328.29 (RESET), C10.1, ICSP.5, RESET.P$2 (2)
BATT: GPS.8 (BATT)
BATT_READ: ARDUINO-ATMEGA328.23 (ANALOG_0), BATT.1, BATT2.2, BATT3.2
DGTL9: ARDUINO-ATMEGA328.13 (DIGITAL_9(PWM)), DGTL_HDR.3
GND: ANLG_HDR1.2, ANLG_HDR2.2, ARDUINO-ATMEGA328.3 (GND1), ARDUINO-ATMEGA328.5 (GND2), ARDUINO-ATMEGA328.21 (GND/ANALOG), BATT2.1, BATT3.1, C1.2, C2.2, C4.1, C5.1, C6.1, C7.1, C8.1, DGTL_HDR.2, EXT_TX.2, FTDI.GND (6), GPS.2 (GND), GPS_DCPLG.2, I2C-1.4, I2C-2.4, ICSP.6, INTERNAL_TEMP.5 (GND), LED_PWR.C, MICRO-SD.6 (GND), MICRO-SD.GND (SHIELD1), MICRO-SD.GND2 (SHIELD2), NTR2.P$2 (GND), NTR2.P$8 (RFGND), NTR2_DCPLG1.1, NTR2_DCPLG2.1, NTR2_RES4.2, OPAMP.4 (V-), P.2, R1.3 (A), RESET.P$1 (1), SD_DCPLG.1, SMA_CONN.G@1 (GND), SMA_CONN.G@2 (GND), SMA_CONN.G@3 (GND), SMA_CONN.G@4 (GND), STATUS_LED.C, TEMPADD.1, TEMPEXT.1, TEMP_DCPLG.1, UP_CAP4.2, UP_RES2.2, UP_RES4.2, VREG.3 (GND), VREG.6 (GND), VREG.7 (GND)
GPS_RX: ARDUINO-ATMEGA328.1 (DIGITAL_3(PWM)), GPS_RES3.1
GPS_TX: ARDUINO-ATMEGA328.2 (DIGITAL_4), GPS.6 (RXB), GPS_RES2.2
I2C_SCL: ARDUINO-ATMEGA328.28 (ANALOG_5), I2C-1.2, I2C-2.2, I2C_RES2.2
I2C_SDA: ARDUINO-ATMEGA328.27 (ANALOG_4), I2C-1.3, I2C-2.3, I2C_RES1.2
MISO: ARDUINO-ATMEGA328.16 (DIGITAL_12), ICSP.1, MISO_RES.2
MOSI: ARDUINO-ATMEGA328.15 (DIGITAL_11(PWM)), ICSP.4, MICRO-SD.3 (DI)
unnamed: C3.2, VREG.4 (BYP)
unnamed: MICRO-SD.7 (DO), MISO_RES.1
unnamed: LED_PWR.A, RES_PWR.1
unnamed: C10.2, FTDI.DTR (1)
unnamed: ARDUINO-ATMEGA328.8 (CRYSTAL2), C5.2, OSC.1
unnamed: ARDUINO-ATMEGA328.7 (CRYSTAL1), C4.2, OSC.3 (2)
unnamed: STATUS_LED.A, STATUS_RES.2
unnamed: ARDUINO-ATMEGA328.31 (DIGITAL_1(TX)), FTDI.RXI (2)
unnamed: ARDUINO-ATMEGA328.30 (DIGITAL_0(RX)), FTDI.TXO (3)
unnamed: ARDUINO-ATMEGA328.14 (DIGITAL_10(PWM)), CS_PULL_UP.2, MICRO-SD.2 (CS)
unnamed: NTR2.P$7 (TXD), NTR2_RES2.2, NTR2_RES3.2, NTR2_RES4.1
unnamed: GPS.3 (RXA), GPS_RES1.1
unnamed: GPS.5 (TXB), GPS_RES3.2
unnamed: OPAMP.3 (+IN), R1.2 (S)
unnamed: NTR2_RES1.2, NTR2_RES2.1
unnamed: OPAMP.5 (+IN), UP_CAP1.2, UP_RES4.1
unnamed: OPAMP.7 (OUT), R2.3 (A), UP_CAP3.1, UP_RES1.2
unnamed: OPAMP.6 (-IN), R2.1 (E), R2.2 (S), UP_CAP3.2, UP_RES2.1
NTR2_AF: NTR2.P$4 (AF), UP_CAP1.1
NTR2_EN: ARDUINO-ATMEGA328.11 (DIGITAL_7), NTR2.P$6 (EN)
NTR2_RSSI: ARDUINO-ATMEGA328.24 (ANALOG_1), NTR2.P$1 (RSSI)
RANDOM: OPAMP.2 (-IN), UP_CAP4.1, UP_RES1.1
RF_IN: NTR2.P$9 (RFOUT), SMA_CONN.1
SCK: ARDUINO-ATMEGA328.17 (DIGITAL_13), ICSP.3, MICRO-SD.5 (SCK), STATUS_RES.1
TEMPERATURE: 1WIRE.1, ARDUINO-ATMEGA328.32 (DIGITAL_2), INTERNAL_TEMP.4 (1W), TEMPADD.2, TEMPEXT.2
TX_0: ARDUINO-ATMEGA328.9 (DIGITAL_5(PWM)), NTR2_RES1.1
TX_1: ARDUINO-ATMEGA328.10 (DIGITAL_6(PWM)), EXT_TX.3, NTR2_RES3.1
UPLINK: ARDUINO-ATMEGA328.12 (DIGITAL_8), OPAMP.1 (OUT)
VBATT: BATT.2, C2.1, NTR2.P$3 (VCC), NTR2_DCPLG1.2, NTR2_DCPLG2.2, P.1, VREG.5 (!SHDN), VREG.8 (IN)
VCC: 1WIRE.2, ANLG_HDR1.1, ANLG_HDR2.1, ARDUINO-ATMEGA328.4 (VCC1), ARDUINO-ATMEGA328.6 (VCC2), ARDUINO-ATMEGA328.18 (VCC/ANALOG), ARDUINO-ATMEGA328.20 (ANALOG_REFERENCE), C1.1, C3.1, C6.2, C7.2, C8.2, CS_PULL_UP.1, DGTL_HDR.1, EXT_TX.1, GPS.7 (VCC), GPS_DCPLG.1, GPS_RES1.2, GPS_RES2.1, I2C-1.1, I2C-2.1, I2C_RES1.1, I2C_RES2.1, ICSP.2, INTERNAL_TEMP.3 (VDD), MICRO-SD.4 (VCC), OPAMP.8 (V+), R1.1 (E), RES_PWR.2, SD_DCPLG.2, TEMPADD.3, TEMPEXT.3, TEMP_DCPLG.2, VREG.1 (OUT), VREG.2 (SENSE)

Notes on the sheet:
POWER
1.0
Priyesh Patel/Daniel Saul
TEMPERATURE
GND
VDD
DS18B20
Apex III Core is a 3V3 board
RADIO
GPS
SPARE HEADERS
STANDOFFS
I2C
UPLINK


Board: 2 copper layers, 99.1 x 49.5 mm, 68 parts (1 on the bottom side), 44 nets.

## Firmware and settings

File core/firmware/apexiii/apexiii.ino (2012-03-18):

/**
 * apexiii.ino
 *
 * Part of the Apex III project
 * http://www.apexhab.org/apex-iii/
 *
 * Priyesh Patel
 *
 * (c) Copyright ApexHAB 2011
 * team@apexhab.org
 */

// Include libraries
#include <SD.h>
//#include <Wire.h>

// Include header files
#include "counter.h"
#include "temperature.h"
#include "gps.h"
#include "rtty.h"
#include "battery.h"
#include "modules.h"
#include "protocol.h"

// Define settings
uint8_t STATUS_LED_PIN = 13;
uint8_t EXT_TEMP_ADDR[8] = {0x28, 0x8D, 0x0C, 0x68, 0x03, 0x00, 0x00, 0xF7};
uint8_t INT_TEMP_ADDR[8] = {0x28, 0x42, 0x99, 0x5E, 0x03, 0x00, 0x00, 0x68};
char SD_LOG_FILENAME[] = "APEXIII.LOG";
char SD_GPS_FILENAME[] = "GPS.LOG";
uint8_t SD_CS = 10;

// Define packet variable
char packet[200];
// Last GPS string with fix
char gps_lastfix[65];
// Current altitude
uint16_t altitude = 0;
// Current command
commands command = NONE;
// Packet type
uint8_t packet_type = 5;

void setup()
{
    // Setup serial
    Serial.begin(9600);

    Serial.println();
    Serial.println("/------------\\");
    Serial.println("|  Apex III  |");
    Serial.println("\\------------/");

    // Initialise status LED and then turn it on
    pinMode(STATUS_LED_PIN,OUTPUT);
    digitalWrite(STATUS_LED_PIN,HIGH);

    // Initialise radio module
    rtty_init();

    // Initialise the SD card
    pinMode(SD_CS, OUTPUT);
    if (!SD.begin(SD_CS)) Serial.println("SD card failed to initialise");

    // Initialise GPS last fix string 
    gps_get(gps_lastfix);

    // System booted
    Serial.println("");
    Serial.println("Apex III successfully booted");
    Serial.println("");

    // Turn status LED off
    digitalWrite(STATUS_LED_PIN,LOW);

    // Blank line to serial
    Serial.println("");
}

void loop()
{
    sdcard_gps();

    // Increment the counter
    counter_inc();

    // Get altitude
    altitude = gps_altitude();

    // Get data from external sensors and devices and then construct the packet
    build_packet();

    // Store sent packet and prepare packet
    rtty_prepare(packet);

    // Print packet to serial
    Serial.print(packet);

    // Write packet to SD card
    sdcard_log(packet); 

    sdcard_gps();

    // Telemetry
    Serial.print("Telemetry started... ");

    delay(100);

    sdcard_gps();

    // Count down the packet type
    packet_type -= 1;
    
    // Send the packet with RTTY
    // @ 300 baud - preamble then 3 times
    rtty_preamble(1);
    rtty_tx("$$APEX\n", 1);
    rtty_tx(packet, 1);
    sdcard_gps();
    rtty_tx(packet, 1);
    sdcard_gps();

    if (packet_type == 0)
    {
        packet_type = 5;
        // @ 50 baud - preamble then 1 time
        rtty_preamble(0);
        rtty_tx("$$APEX\n", 0);
        rtty_tx(packet, 0);
    }

    Serial.println("finished");
    
    sdcard_gps();

    // Delay until the next packet
    // This window is also for UART commands to be entered in
    delay(2000);
    sdcard_gps();
    delay(2000);

    // Check for any inputted UART commands
    uart_commands();
}

/**
 * Build the packet
 */
void build_packet()
{
    // Broadcast to modules
    modules_broadcast(altitude, command);
    command = NONE;

    // External temperature sensor
    char external_temp[10];
    dtostrf(temperature_get(EXT_TEMP_ADDR),4,2,external_temp);
    // Internal temperature sensor
    char internal_temp[10];
    dtostrf(temperature_get(INT_TEMP_ADDR),4,2,internal_temp);

    // Battery voltage
    char battery_voltage[10];
    dtostrf(battery_get_voltage(),4,2,battery_voltage);

    // GPS 
    char gps_data[65];
    gps_get(gps_data); 
    // If no fix, return last fix
    if (strcmp(gps_data, ",,,,,") == 0)
    {
        strcpy(gps_data, gps_lastfix);
    }
    else
    {
        strcpy(gps_lastfix, gps_data);
    }

    // Reminder - bytes from modules may need casting as int/uint

    // Light A
    char light_a[MODULES_BUFFER_LENGTH];
    modules_request(light_a, LGTA, altitude);
    
    // Gas 
    char gas[MODULES_BUFFER_LENGTH];
    modules_request(gas, GASS, altitude);

    // Light B
    char light_b[MODULES_BUFFER_LENGTH];
    modules_request(light_b, LGTB, altitude);
    uint16_t light_red = (light_a[3] << 8) | (light_a[2]);
    uint16_t light_green = (light_a[5] << 8) | (light_a[4]);
    uint16_t light_blue = (light_b[3] << 8) | (light_b[2]);
    uint16_t light_normal = (light_b[5] << 8) | (light_b[4]);

    // Build the packet
    sprintf(packet,"$$APEX,%u,%s,%s,%s,%u,%u,%u,%u,%u,%u,%s",
        counter_get(),
        gps_data,
        external_temp,
        internal_temp,
        light_normal,
        light_red,
        light_green,
        light_blue,
        (uint8_t) gas[2],
        (uint8_t) gas[3],
        battery_voltage
    );
}

/**
 * Write sentence to SD card log 
 */
void sdcard_log(char* sentence)
{
    File logFile = SD.open(SD_LOG_FILENAME, FILE_WRITE);
    
    if (logFile)
    {
        logFile.print(sentence);
    }

    logFile.close();
}

/**
 * Write GPS data to SD card
 */
void sdcard_gps()
{
    File logFile = SD.open(SD_GPS_FILENAME, FILE_WRITE);
    
    if (logFile)
    {
        char buffer_gpgga[90];
        gps_nmea(buffer_gpgga, "GPGGA");
        logFile.println(buffer_gpgga);
        char buffer_gpvtg[90];
        gps_nmea(buffer_gpvtg, "GPVTG"); 
        logFile.println(buffer_gpvtg);
    }

    logFile.close();
}

/**
 * Check for any commands via UART 
 */
void uart_commands()
{
    if(Serial.available() >= 4)
    {
        // A $ signifies the start of a 3 character command
        while ((Serial.available() > 0) && (Serial.read() != '$')) {}

        if (Serial.available() >= 3)
        {
            char data[4];
            for (int i=0; i<3; i++)
            {
                data[i] = Serial.read();
            }
            data[3] = 0;
            
            uart_commands_parse(data);
        }
    }

    Serial.flush();
}

/**
 * Parse UART command 
 */
void uart_commands_parse(char* cmd)
{
    if (strcmp(cmd, "RTC") == 0)
    {
        counter_reset();
    }
    else if (strcmp(cmd, "CDN") == 0)
    {
        command = CDWN;
    }
    else if (strcmp(cmd, "SN0") == 0)
    {
        command = SRN0;
    }
    else if (strcmp(cmd, "SN1") == 0)
    {
        command = SRN1;
    }
    else if (strcmp(cmd, "PNG") == 0)
    {
        command = PING;
    }
    else if (strcmp(cmd, "ALT") == 0)
    {
        command = ALTR;
    }
}

//float humidity()
//{
//    // Begin I2C
//    Wire.begin();
//
//    // Begin transmission to the sensor and ask for humidity data
//    Wire.beginTransmission(0x40);
//    Wire.write(0xE5);
//    Wire.endTransmission();
//    delay(2);
//
//    // Request data from sensor
//    Wire.requestFrom(0x40, 2);
//
//    unsigned int msb;
//    unsigned int lsb;
//    float data;
//
//    // Read data
//    while (!Wire.available());
//    msb = Wire.read();
//    while (!Wire.available());
//    lsb = Wire.read();
//
//    //twi_releaseBus();
//    TWCR = _BV(TWEN) | _BV(TWIE) | _BV(TWEA) | _BV(TWINT);
//
//    // Convert data into sensible units
//    data = (msb * 256) + lsb;
//    data = ((data/65536) * 125) - 6;
//
//    return data;
//}

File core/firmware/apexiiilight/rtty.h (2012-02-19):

/**
 * rtty.h
 *
 * Part of the Apex III project
 * http://www.apexhab.org/apex-iii/
 *
 * Priyesh Patel
 *
 * (c) Copyright ApexHAB 2011
 * team@apexhab.org
 */

/*
 * Bauds:
 *  default = 50 baud
 *  0 = 50 baud
 *  1 = 300 baud
 */

#ifndef RTTY_H
#define RTTY_H

#include "Arduino.h"
#include "util/crc16.h"

#define TX_0 5
#define TX_1 6
#define NTR2_EN 7

void rtty_init();
void rtty_prepare(char* sentence);
void rtty_tx(char* sentence, int baud);
void rtty_preamble(int baud);
void rtty_tx_byte(char c, int baud);
void rtty_tx_bit(int b, int baud);
uint16_t rtty_crc16_ccitt_checksum(char* sentence);

#endif

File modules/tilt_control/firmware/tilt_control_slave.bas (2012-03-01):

'/**
' * tilt_control_slave.bas
' *
' * Part of the Apex III project
' * http://www.apexhab.org/apex-iii/
' *
' * Daniel Saul
' *
' * (c) Copyright ApexHAB 2011
' * team@apexhab.org
' */

symbol POTPOSITION = b0
symbol COMMAND = b1
symbol ORIENTATION = b2

symbol UP = 1
symbol SIDE = 0

SYMBOL POTUP = 42
SYMBOL POTSIDE = 105

ORIENTATION = SIDE

SYMBOL PWMPIN = 2
SYMBOL DIRPIN = 0
SYMBOL PERIOD = 1000
SYMBOL DUTY = w3
low PWMPIN
low DIRPIN

main:
  
    if pin4 = 1 then gosub rotateToUp
    if pin4 = 0 then gosub rotateToSide
  
    
    goto main

rotateToUp:
    
    readadc 1,POTPOSITION
    if POTPOSITION < POTUP then
        ORIENTATION = UP
        return
    endif

    high DIRPIN

    DO UNTIL POTPOSITION < POTUP
        readadc 1,POTPOSITION
        DUTY = POTPOSITION
        DUTY = DUTY * 2 max 400
        pwmout PWMPIN, 100, DUTY
    LOOP

    low DIRPIN
    pwmout PWMPIN, OFF

    ORIENTATION = UP
    return
    
rotateToSide:
    
    readadc 1,POTPOSITION
    if POTPOSITION > POTSIDE then
        ORIENTATION = SIDE
        return
    endif

    low DIRPIN

    DO UNTIL POTPOSITION > POTSIDE
        readadc 1,POTPOSITION
        DUTY = 189 - POTPOSITION - 42
        DUTY = DUTY * 3 max 400
        'DUTY = 400
        pwmout PWMPIN, 100, DUTY
        
    LOOP

    low DIRPIN
    pwmout PWMPIN, OFF

    ORIENTATION = SIDE
    return
    

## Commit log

2011-12-09 progress with apex iii core sch
    [apex-iii-core.sch]
2011-12-29 slight changes to schematic
    [apex-iii-core.sch]
2011-12-31 final core schematic
    [apex-iii-core.sch]
2011-12-31 i2c resistors
    [apex-iii-core.sch]
2011-12-31 end of day commit - board very messy
    [apex-iii-core.brd, apex-iii-core.sch]
2012-01-02 core pcb
    [apex-iii-core.brd]
2012-01-03 continued with PCB + readme
    [apex-iii-core.brd]
2012-01-04 pcb mainly finished
    [apex-iii-core.brd, apex-iii-core.sch]
2012-01-04 Core pcb finished
    [apex-iii-core.brd]
2012-01-05 core pcb sent to fab house
    [apex-iii-core.brd, apex-iii-core.sch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]
2012-01-14 setup module folders
    [apex-iii-core.brd, apex-iii-core.sch]
2012-01-14 finished siren
    [siren.brd, siren.sch]
2012-01-14 added cutdown to siren
    [siren_cutdown.brd, siren_cutdown.sch]
2012-01-15 pressure + himidity boards
    [pressure-balloon.brd, pressure-balloon.sch, pressure-humidity-main.brd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]
2012-01-15 siren pcb
    [siren_cutdown.brd]
2012-01-15 Added ADC, Radiation and tilt control module schematics & PCBs
    [Rad-detector.brd, Rad-detector.sch, citrusfruits.brd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]
2012-01-15 fix airwires, rename, export larger pngs
    [adc_lemon.brd, adc_lemon.sch, radiation.brd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]
2012-01-15 Finished light sensor module
    [light.brd, light.sch]
2012-01-15 light module finished
    [light.brd, light.sch]
2012-01-18 module gerbers sent off
    [adc_lemon.brd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]
2012-02-11 upgraded core firmware to arduino 1.0
2012-02-11 clean up + added ground speed
2012-02-16 ext temp sensor address
2012-02-18 improving core firmware and module framework
2012-02-19 module framework added
2012-02-19 updated module framework
2012-02-21 Tilt control firmware finished, pending check of PWM values
2012-02-21 Started ADC lemon firmware
2012-02-22 added pressure firmware and tidied up
2012-02-22 added pressure code to core
2012-02-24 bug fix by casting char
    [apexiii.ino]
2012-02-25 Fixed tilt control syntax error
    [tilt_control_slave.bas]
2012-02-25 Light sensor firmware finished
2012-02-26 Core: changed callsign, changed sentence terminator, removed pressure for now
2013-03-24 light firmware for core board and updated libraries

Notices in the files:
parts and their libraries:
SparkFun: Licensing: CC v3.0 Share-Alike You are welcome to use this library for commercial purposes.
